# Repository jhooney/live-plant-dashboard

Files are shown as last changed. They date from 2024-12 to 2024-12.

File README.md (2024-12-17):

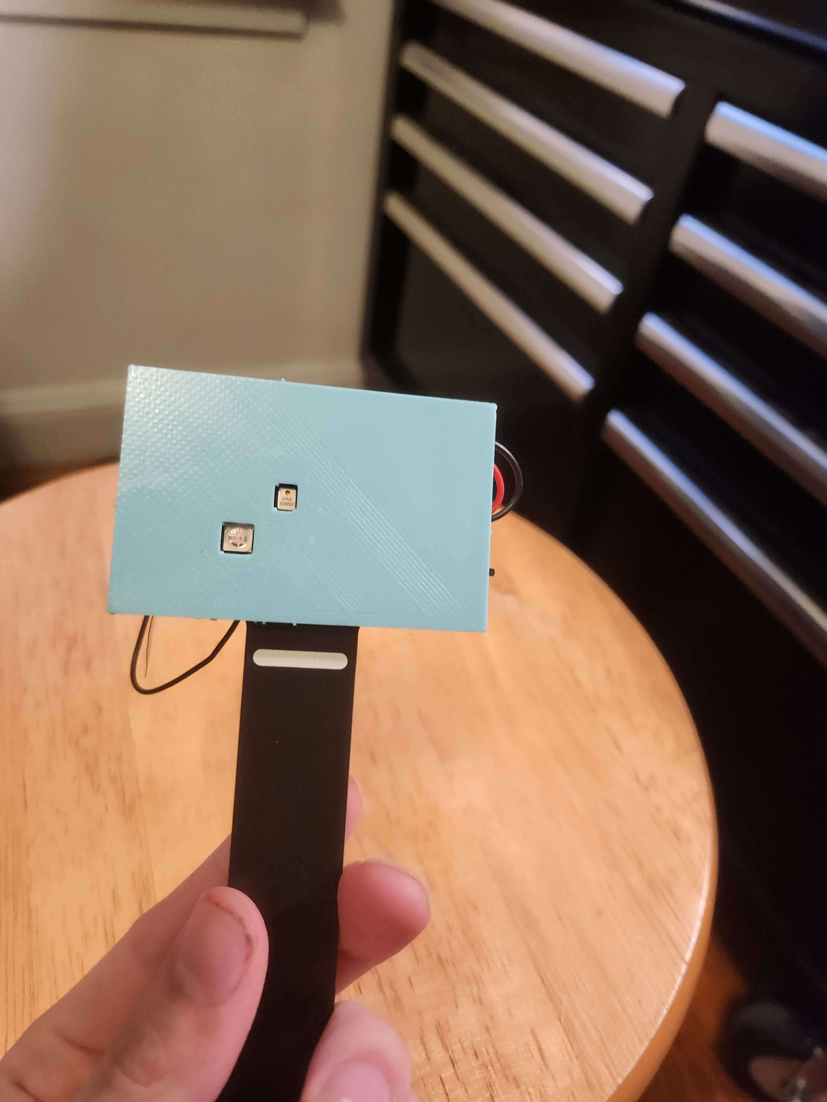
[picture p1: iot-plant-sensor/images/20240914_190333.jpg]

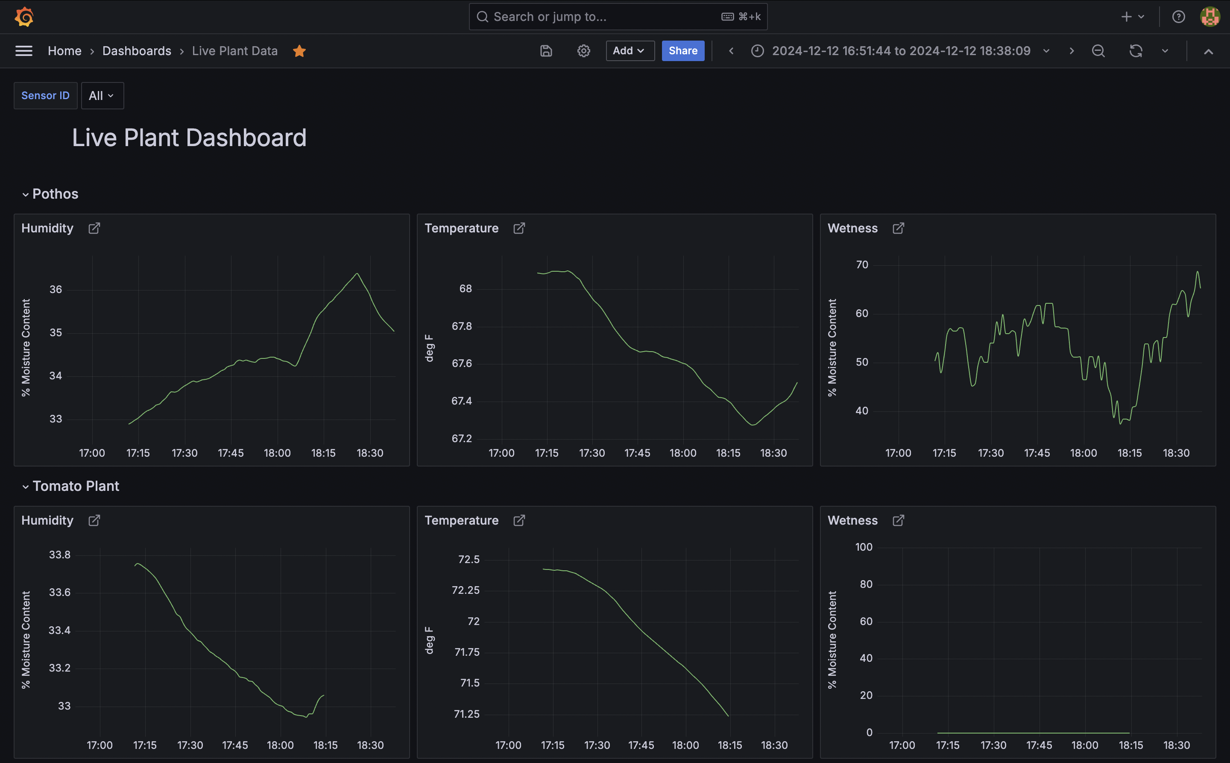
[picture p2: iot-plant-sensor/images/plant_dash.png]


### Live Plant Dashboard

I am creating this project as a three year anniversary gift to my partner. She has dozens of plants, but occasionally will forget to water one for a little while, or will go on vacation and get her watering cycle tripped up. So I have taken the clear next step, create a dozen cheap IOT devices that measure critical plant data, have them all report that data to a central home server so they can be recorded in a time series database, and then create a useful dashboard to display that data and keep tabs on her plants.

### Misc images to help if someone out there tries to replicate
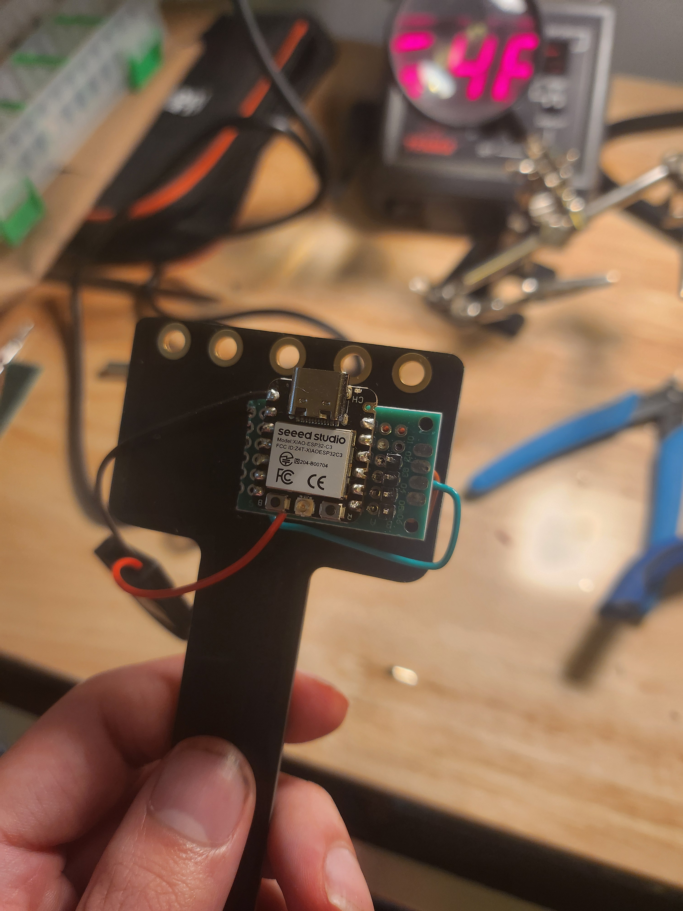
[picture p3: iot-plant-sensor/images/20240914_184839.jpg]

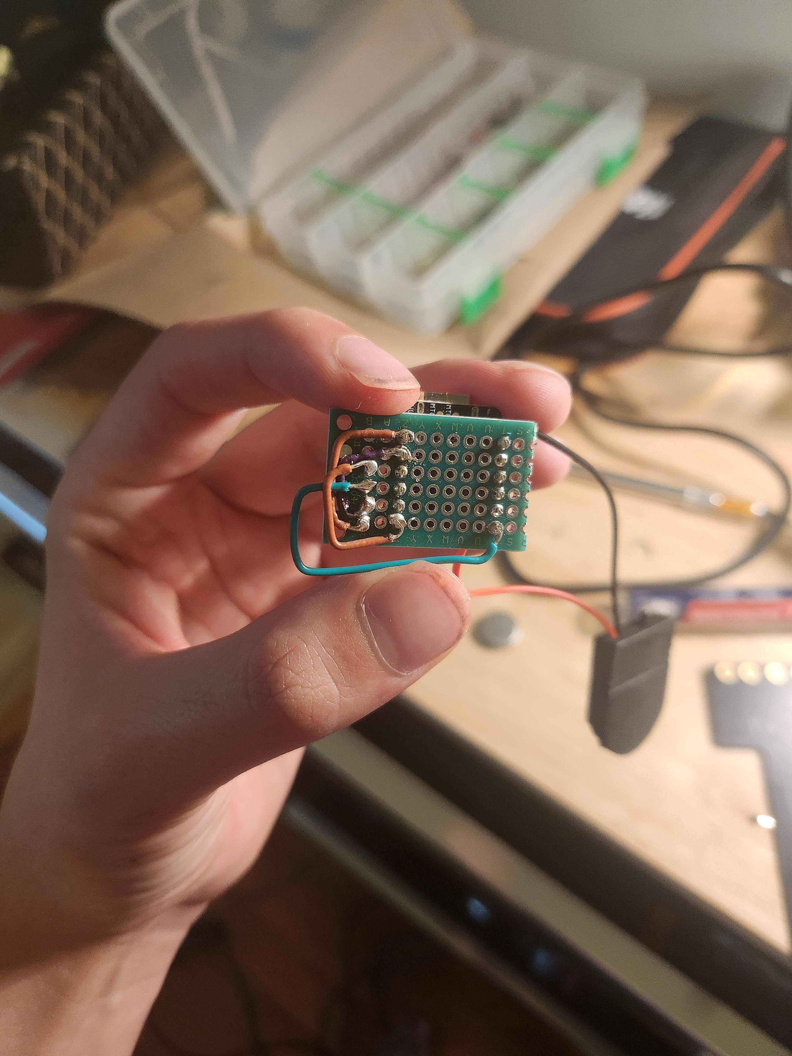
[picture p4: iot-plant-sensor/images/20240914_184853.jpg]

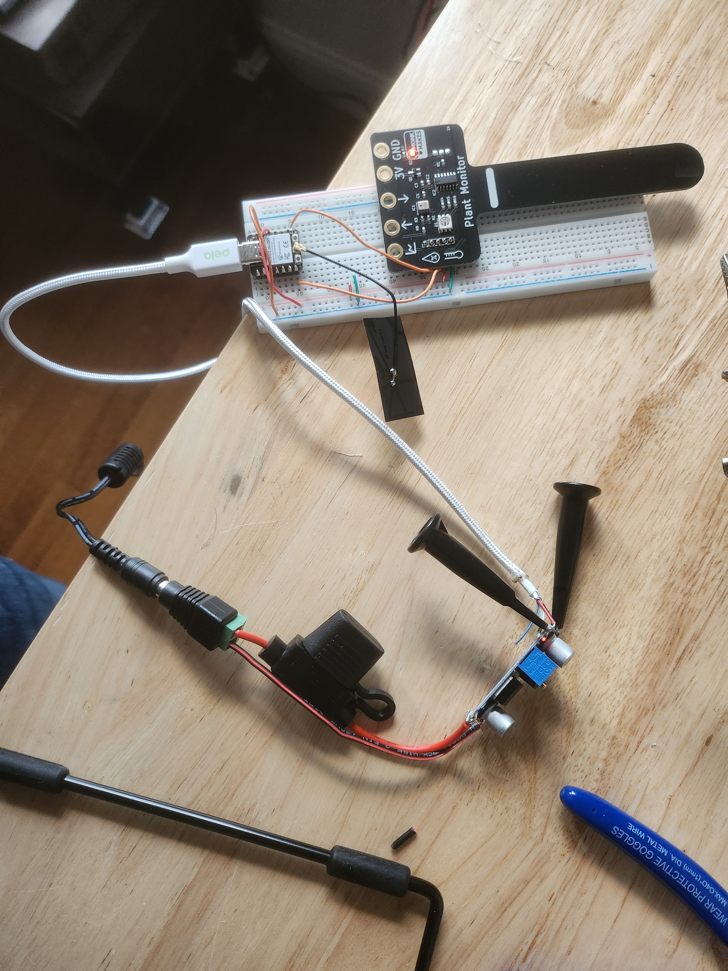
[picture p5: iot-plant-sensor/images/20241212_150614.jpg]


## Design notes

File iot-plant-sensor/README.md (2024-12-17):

## General Description of Project Hardware
The iot devices (of which I am building a dozen to start) are fairly simple and compose of the monk makes plant monitor: https://monkmakes.com/pmon
and the Seeed Studio XIAO ESP32C3. The plant monitor is recording humidity, temperature, and light. The esp32 pulls the plant monitor every minute for data, and then report that do a prometheus database running on a home server (which is just a Beelink mini PC on our home wifi)

## Powering the Seeed Studio ESP32C3
The Seeed Studio ESP32C3 has issues on some boards with powering over battery, so I have resorted to powering them all over USB C. I am using a AC to DC converter that I had in the drawer from a previous project. This powers the board at 12V so I have connected it to a buck converter which is then soldered to a bunch of cheap USB-C cables cut in half. Photos below and CAD files in the 3D files folder. I also put attached a fuse to the DC input just in case.

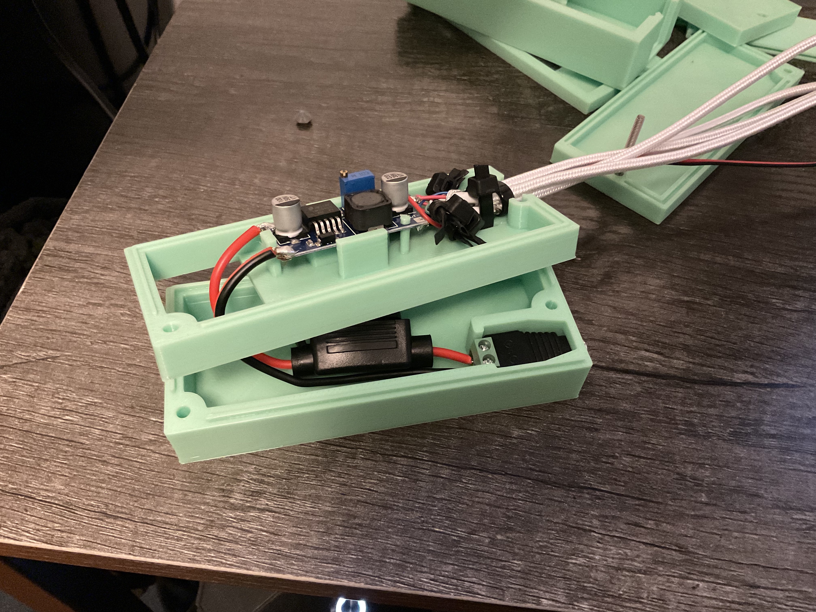
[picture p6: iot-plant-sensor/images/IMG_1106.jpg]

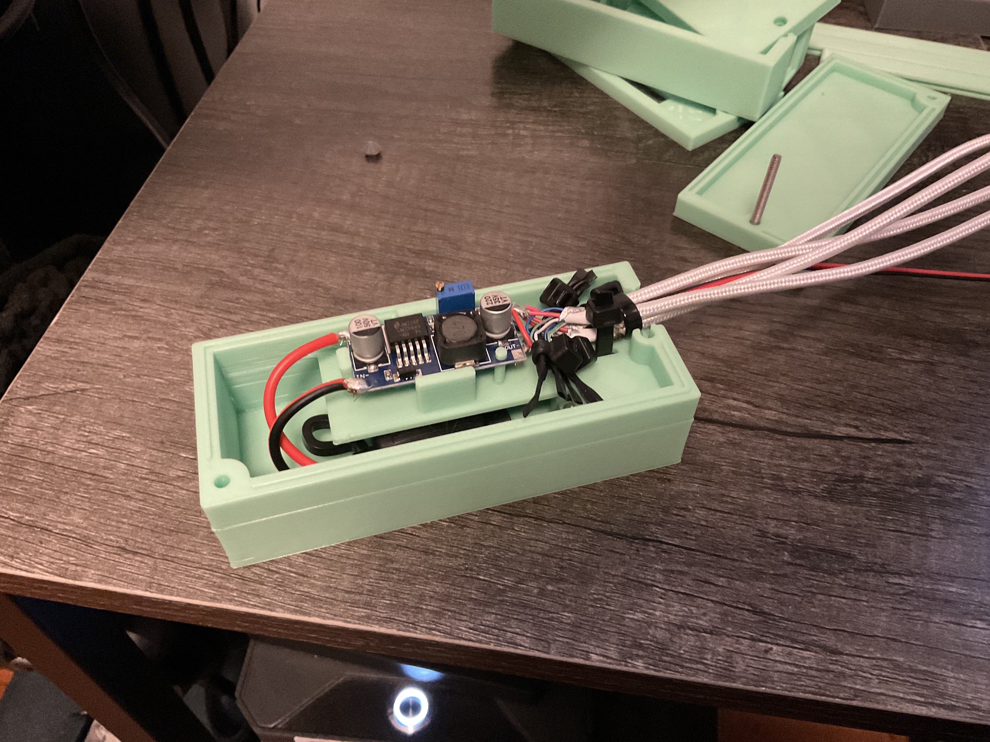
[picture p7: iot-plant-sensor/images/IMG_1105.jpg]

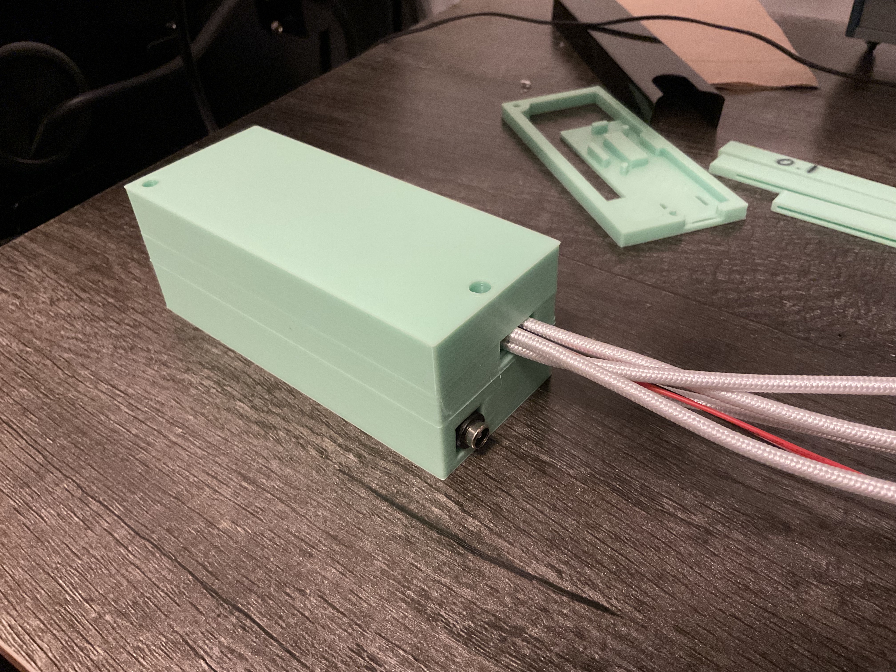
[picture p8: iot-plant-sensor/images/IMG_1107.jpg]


These components are attached with 5-40 screws. iirc they are 1 1/4".

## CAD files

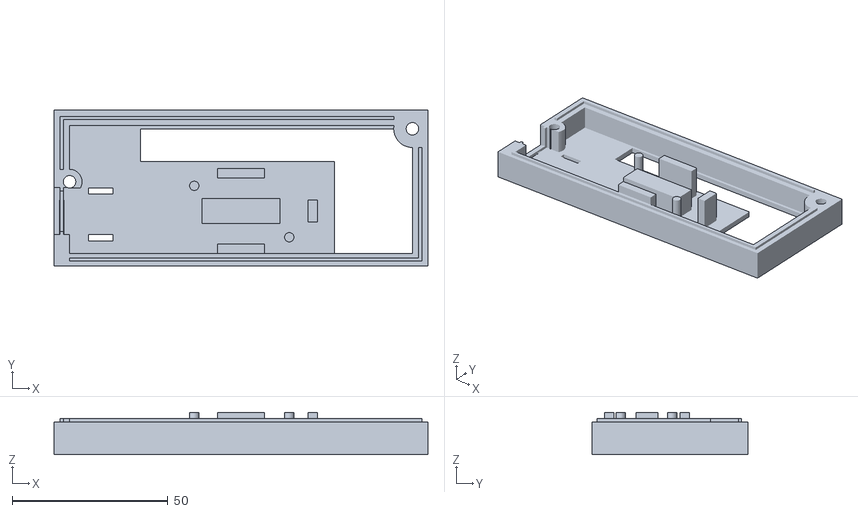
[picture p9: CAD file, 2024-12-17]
iot-plant-sensor/3D Files/Power Squid Case - Mid section.stl
120.0 x 50.0 x 13.5

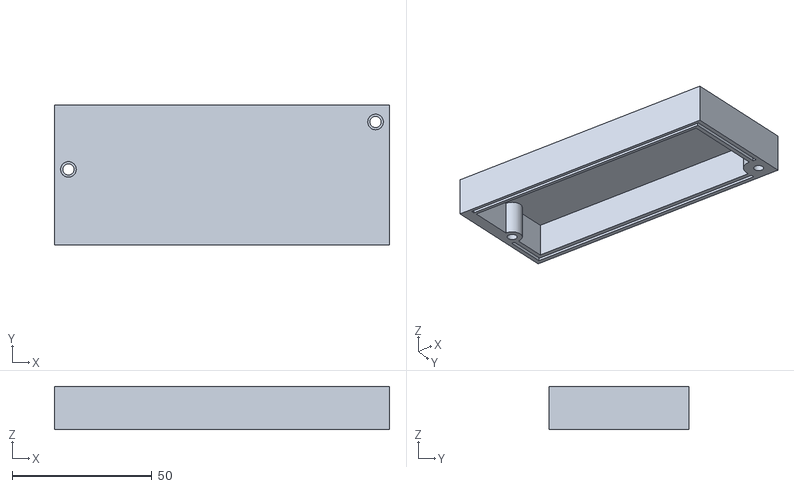
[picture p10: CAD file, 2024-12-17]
iot-plant-sensor/3D Files/Power Squid Case - Top section.stl
120.0 x 50.0 x 15.5

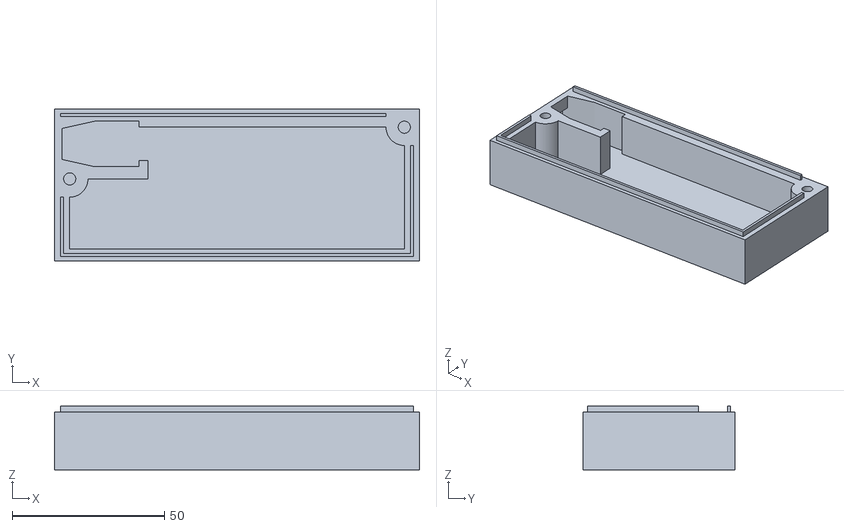
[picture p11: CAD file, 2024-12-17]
iot-plant-sensor/3D Files/Power Squid Case - Lower section.stl
120.0 x 50.0 x 21.0

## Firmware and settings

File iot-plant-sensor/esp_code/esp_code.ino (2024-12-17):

/*
 * Smart device monitoring plant health
 * Running on XIAO-ESP32-C3
 * Talking to Monk Makes Plant Monitor
 * Reporting data over WiFi to Raspberry Pi via MQTT
 */

#include <WiFiMulti.h>
WiFiMulti wifiMulti;
#include <ArduinoJson.h>
#include <production-secrets.h>
//#include <testing-secrets.h>
#include <InfluxDbClient.h>
#include <InfluxDbCloud.h>

#define RX_PIN D7 //in
#define TX_PIN D6 //out
#define DEVICE_ID "4" //CHANGE PER DEVICE

#define WIRED_MODE false //cannot use Serial in battery mode on this board so need to disable

// Time zone info
#define TZ_INFO "UTC-5"

// Declare InfluxDB client instance with preconfigured InfluxCloud certificate
InfluxDBClient client(INFLUXDB_URL, INFLUXDB_ORG, INFLUXDB_BUCKET, INFLUXDB_TOKEN, InfluxDbCloud2CACert);

Point sensor("plant_monitors");

unsigned long previousMillis = 0;   // Stores the last time 'j' was sent
const long interval = 60000;        // Interval at which to send 'j' (60 seconds)
unsigned long timeSinceTimeReset = 0; // Stores last time reset time interval
const long resync_time_interval = 600000;        // Interval at which to send 'j' (10 minutes)

String influx_writing_values; //used to track influx db communication
bool influx_write_status;

void setup_wifi() {
  WiFi.mode(WIFI_STA);
  wifiMulti.addAP(WIFI_SSID, WIFI_PASS);

  if(WIRED_MODE){
    Serial.println();
    Serial.print("Connecting to ");
    Serial.println(WIFI_SSID);
  }
  
  while (wifiMulti.run() != WL_CONNECTED) {
    if(WIRED_MODE){
      Serial.print(".");
    }
    delay(100);
  }

  if(WIRED_MODE){
    Serial.println("");
    Serial.println("WiFi connected");
    Serial.println("IP address: ");
    Serial.println(WiFi.localIP());
  }
}

void turn_led_off() {
    if(WIRED_MODE){Serial.println("Turning LED off");}
    Serial1.print("l");
}

void setup() {
  if(WIRED_MODE){
    // Initialize Serial Monitor
    Serial.begin(115200);
  }

  setup_wifi();
  
  // Accurate time is necessary for certificate validation and writing in batches
  // We use the NTP servers in your area as provided by: https://www.pool.ntp.org/zone/
  // Syncing progress and the time will be printed to Serial.
  timeSync(TZ_INFO, "pool.ntp.org", "time.nis.gov");

  if(WIRED_MODE){
    // Check server connection
    if (client.validateConnection()) {
      Serial.print("Connected to InfluxDB: ");
      Serial.println(client.getServerUrl());
    } else {
      Serial.print("InfluxDB connection failed: ");
      Serial.println(client.getLastErrorMessage());
    }
  }
    
  // Add tags to the data point
  sensor.addTag("device", DEVICE_ID);
  sensor.addTag("SSID", WiFi.SSID());

  // Initialize Serial1 (UART) for RS232 communication
  Serial1.begin(9600, SERIAL_8N1, RX_PIN, TX_PIN);
  if(WIRED_MODE){Serial.println("Serial communication with RS232 device started.");}
}

void loop() {
  // Ensure the InfluxDB client is still connected
  if (wifiMulti.run() != WL_CONNECTED) {
    setup_wifi(); // Reconnect to WiFi if disconnected
  }
  
  // Clear fields for reusing the point. Tags will remain the same as set above.
  sensor.clearFields();

  unsigned long currentMillis = millis();

  // Check if it's time to resync time value
  if (currentMillis - timeSinceTimeReset >= resync_time_interval) {
    if(WIRED_MODE){Serial.println("resyncing time value");}
    timeSync(TZ_INFO, "pool.ntp.org", "time.nis.gov"); //re-sync time
    timeSinceTimeReset = currentMillis;
  }
  
  // Check if it's time to send 'j'
  if (currentMillis - previousMillis >= interval) {
    previousMillis = currentMillis;
    Serial1.print('j');
    if(WIRED_MODE){Serial.println("Sent 'j' to RS232 device.");}
  }

  // Read data from the RS232 device
  if (Serial1.available()) {
    String dataFromRS232 = Serial1.readString();
    if(WIRED_MODE){
      Serial.print("Received from RS232: ");
      Serial.println(dataFromRS232);
    }
  
    // Parse the received JSON
    StaticJsonDocument<200> doc;  // Adjust the size as needed
    DeserializationError error = deserializeJson(doc, dataFromRS232);

    turn_led_off();
    
    if (!error) {
      // Add the device_id field
      doc["device_id"] = DEVICE_ID;

      // Extract sensor data from the JSON
      float wetness = doc["wetness"];
      float humidity = doc["humidity"];
      float temp = doc["temp"];

      // Add tags and fields
      sensor.clearFields();
      sensor.addField("wetness", wetness);
      sensor.addField("humidity", humidity);
      sensor.addField("temperature", temp);
      sensor.addField("signal_strength", WiFi.RSSI());

      influx_writing_values = sensor.toLineProtocol();
      if(WIRED_MODE){
        // Print what are we exactly writing
        Serial.print("Writing: ");
        Serial.println(influx_writing_values);
      }

      influx_write_status = client.writePoint(sensor);

      if(WIRED_MODE){
        // Write the point to InfluxDB
        if (influx_write_status) {
          Serial.println("Data written to InfluxDB successfully.");
        } else {
          Serial.print("InfluxDB write failed: ");
          Serial.println(client.getLastErrorMessage());
        }
      }
    } else {
      if(WIRED_MODE){
        Serial.print("Failed to parse JSON: ");
        Serial.println(dataFromRS232);
      }
    }
  }

  if(WIRED_MODE){
    // If data is available on the Serial Monitor, send it to the RS232 device
    if (Serial.available()) {
      String dataToRS232 = Serial.readString();
      Serial1.print(dataToRS232);
      Serial.print("Sent to RS232: ");
      Serial.println(dataToRS232);
    }
  }
}

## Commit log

2024-09-11 added node red and updated arduino code
2024-09-11 switched to one docker compose
2024-09-11 added node flow
2024-09-22 esp code working while wired services simplified
2024-12-17 code is functional, added images and descriptions.
    [Power Squid Case - Lower section.stl, Power Squid Case - Mid section.stl, Power Squid Case - Top section.stl]
